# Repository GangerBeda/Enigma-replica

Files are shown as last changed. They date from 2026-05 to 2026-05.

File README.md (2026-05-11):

# Pico Enigma (MicroPython) – quick build & wiring guide

---

## 1) Parts checklist and central circuit setup

- Raspberry Pi Pico W
- 4× PCF8574 I²C GPIO expanders  
  - 2× for keyboard matrix  
  - 2× for LED matrix
- 3×9 key matrix (26 keys) wired as rows/columns
- 3×9 LED matrix / lampboard (26 LEDs, matrix wired)
- LCD1602 (HD44780) with I²C backpack (PCF8574)
  - Commonly available LCD displays with these specifications should fit, but just in case, this is the one used during development: <https://dratek.cz/arduino-platforma/1570-iic-i2c-display-lcd-1602-16x2-znaku-lcd-modul-modry.html>
- Half-sized breadboard, wires
- Resistors ~200 Ω for LEDs (For LED matrix at least 3 resistors)

- Put the microcontroller on the breadboard and connect any **GND** and **Vcc** to a bus strip and ground rail of the breadboard, using which you will power the individual subsystems.
- The 'box' model is the main casing component. Facing the front of the model, put the slotted breadboard to the back-right corner of the model.

---

## 2) 3D printed parts

- Print all the 3D parts in the 'Models' directory and its subdirectories.
- The models are made to be printed simply without supports. You can print with PLA, PETG, ABS, or virtually anything, but since some models have a large first layer, I recommend printing with PLA for simplicity and with a brim.
- You can assemble the subsystems along the way.

---

## 3) I²C buses and Pico pins

This project uses **two hardware I²C buses** plus one **SoftI²C**:

### Keyboard expanders (I²C0)
- Pico **GP0 = SDA0**
- Pico **GP1 = SCL0**
- PCF8574 addresses: **0x20** and **0x21**

### LED matrix expanders (I²C1)
- Pico **GP14 = SDA1**
- Pico **GP15 = SCL1**
- PCF8574 addresses: **0x22** and **0x23**

### LCD1602 (SoftI²C, separate)
- Pico **GP10 = SDA**
- Pico **GP11 = SCL**
- LCD backpack address: usually **0x27**

> All devices on the same I²C bus share SDA/SCL, but must have unique addresses.

---

## 4) PCF8574 address setup

PCF8574 boards have address jumpers A0/A1/A2.

Set them so you get:
- Keyboard: **0x20**, **0x21**
- LED: **0x22**, **0x23**
- LCD backpack: **0x27** (fixed by backpack or solder pads)

---

## 5) Keyboard assembly
- Install the key switches onto the 'keyboard' model.
- Wire the keyboard switches together into a matrix according to the following diagram.
              - diagram
- Slot the PCF8574 expanders into the 'keyboard circuitry' model via zipties or adhesive and secure the keyboard circuitry to the keyboard with the 'keyboard pivot'.

Keyboard uses two expanders:

### PCF8574 @ 0x20 (rows + cols 5–8)
- **P7 = row0**
- **P6 = row1**
- **P5 = row2**
- **P4 = col8**
- **P3 = col7**
- **P2 = col6**
- **P1 = col5**
- **P0 = unused**

### PCF8574 @ 0x21 (cols 0–4)
- **P4 = col4**
- **P3 = col3**
- **P2 = col2**
- **P1 = col1**
- **P0 = col0**

How to wire it physically:
- Connect each of the 3 **row wires** from your key matrix to the row pins above.
- Connect each of the 9 **column wires** to col0..col8 pins above.

- This completes the keyboard and you can now insert it into the 'box' casing.

---

## 6) LED “lampboard” assembly

- Print 26 of the 'led cup' models. Each of them has 2 openings at the base for LED terminals, one of which is marked with a + symbol for the anode.
- Prepare your 26 'led cups' by putting an LED in each one.
- Slot the 'led cups' in the 'lampboard frame' and solder them together according to the following diagram

    - diagram

### Circuit setup
LED matrix uses two expanders:

### PCF8574 @ 0x22 (columns 0–5)
- **P0 = col0** (hardware “col1”)
- **P1 = col1**
- **P2 = col2**
- **P3 = col3**
- **P4 = col4**
- **P5 = col5**
- **P6, P7 = unused**

### PCF8574 @ 0x23 (columns 6–8 + rows)
- **P0 = col6**
- **P1 = col7**
- **P2 = col8**
- **P3, P4 = unused**
- **P5 = row0**
- **P6 = row1**
- **P7 = row2**

How to wire it physically:
- Put the PCF8574 expanders in their slot on the 'lampboard circuitry' model and secure it with zip ties or adhesive. Then, attach the slotted lampboard circuitry to the wired lampboard frame.
- Connect the 3 **LED matrix row lines** to P5–P7 of **0x23**.
  - For the 3 rows, connect them to the expander via the 3 resistors. **This is important**, as without them, the LEDs will break.
- Connect LED matrix columns:
  - col0–col5 to **0x22 P0–P5**
  - col6–col8 to **0x23 P0–P2**

Polarity note:
- If **all lamps turn on at boot**, your matrix polarity is inverted relative to the default drive mode. The project has an **invert** option in the driver to fix this without rewiring.

---

## 7) LCD1602 wiring (I²C backpack)
- Slide the display into the 'display slot' model and connect it to the MCU.

- **SDA → GP10**
- **SCL → GP11**
- **VCC/GND** as required by your module
- The characters may not be visible at first. In that case, you can adjust the contrast using a potentiometer on the backpack of the display with a screwdriver.
  - Additionally, if you're powering the display with 3.3 V, you can try switching to 5 V, which should work better with LCD displays.
- Adjust the **contrast potentiometer** on the backpack if the backlight is on but characters are not visible.

- Attach the completed display slot to the lampboard frame.
  - This completes the lampboard. You can now put it into the 'box' casing model.
  - The replica should now be complete. Once you're done wiring the components to the MCU, you can put the 'box back' model on the back of the model and the 'keyboard lid' between the keyboard and the lampboard to seal the machine and the replica is completed.

---

## 8) Loading the program
- The replica has a small opening in the back. Use that to connect the Pico W to a computer.
- Install MicroPython firmware on the Pico W
  - Download the **Pico W** `.uf2` from
     <https://micropython.org/download/rp2-pico-w/>
  - Hold BOOTSEL, connect USB, drag the `.uf2` onto the `RPI-RP2` drive.
- Copy all eight source files from `micropython/` to the **root** of the Pico W filesystem.
  - Edit the 'wifi_config.py' file by inputing the ssid and password to your WiFi. This is needed for configuration.
  - You can use Thonny IDE to do this: Open each file from micropython/ -> Save As... -> Raspberry Pi Pico

- Once done, reset the controller and the program will run on startup, connect to the WiFi and display an IP address. Open the machine's address in a web browser (http). There, you'll find a configuration interface with instructions, which you can use to configure the machine's initial state.

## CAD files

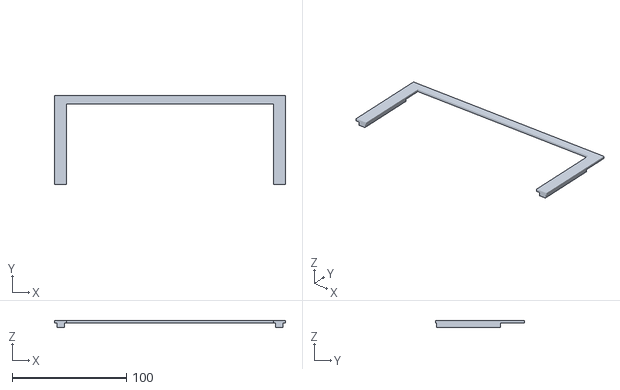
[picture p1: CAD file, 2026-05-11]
models/keyboard lid.stl
202.4 x 78.2 x 6.00

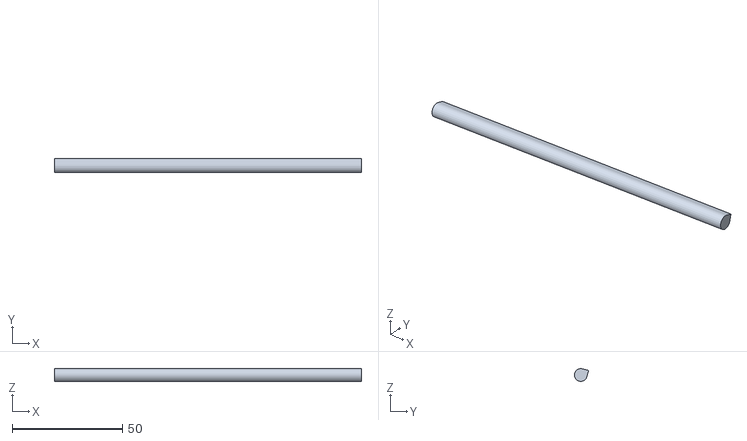
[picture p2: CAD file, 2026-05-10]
models/Keyboard/keyboard pivot.stl
139.0 x 6.45 x 5.80

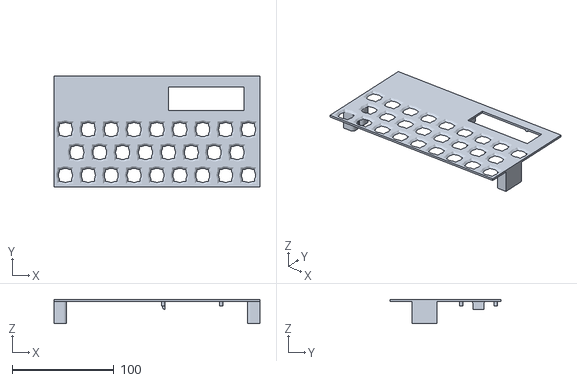
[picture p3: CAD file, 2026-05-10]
models/Lampboard/lampboard frame.stl
202.5 x 108.8 x 24.0

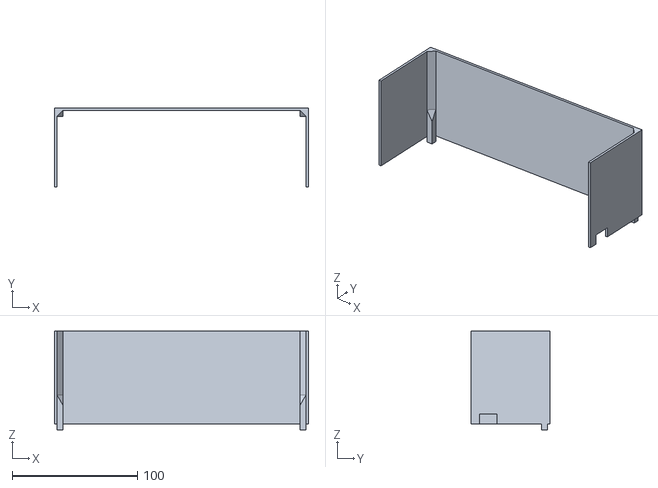
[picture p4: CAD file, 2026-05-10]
models/box back.stl
202.5 x 63.3 x 78.8

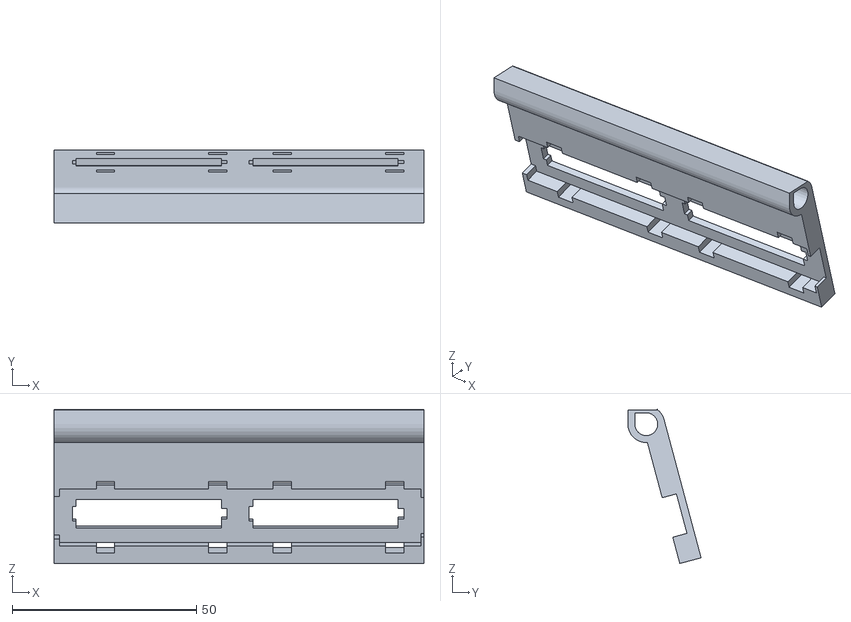
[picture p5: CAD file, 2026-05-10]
models/Keyboard/keyboard circuitry.stl
100.5 x 19.9 x 41.8

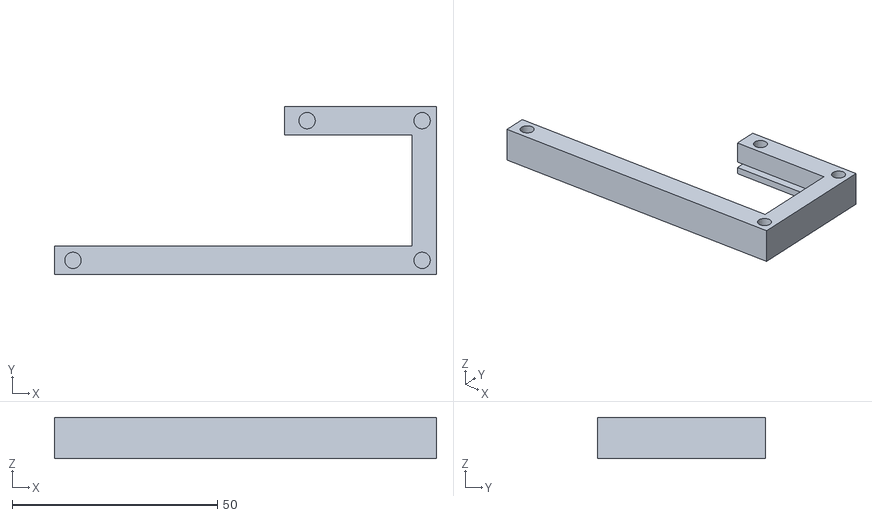
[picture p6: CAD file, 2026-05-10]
models/Lampboard/display slot.stl
93.0 x 41.0 x 10.0

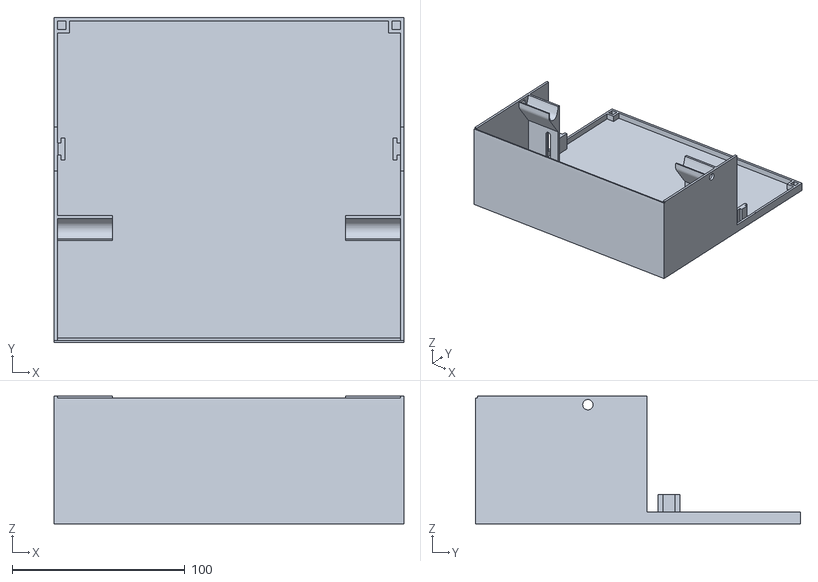
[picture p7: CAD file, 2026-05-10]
models/box.stl
202.5 x 188.0 x 74.0

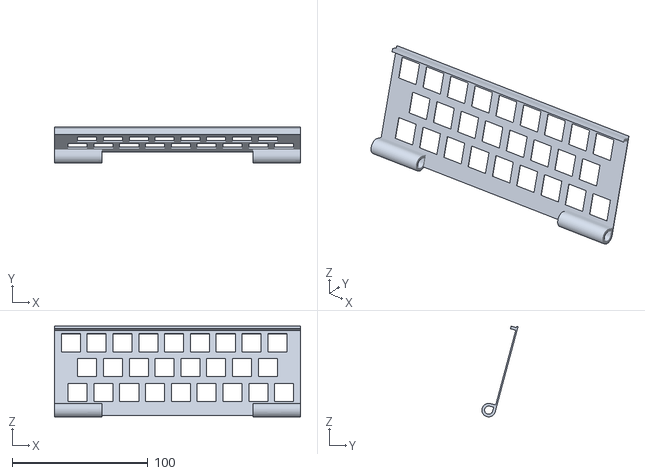
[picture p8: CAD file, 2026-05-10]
models/Keyboard/keyboard.stl
181.0 x 26.6 x 66.8

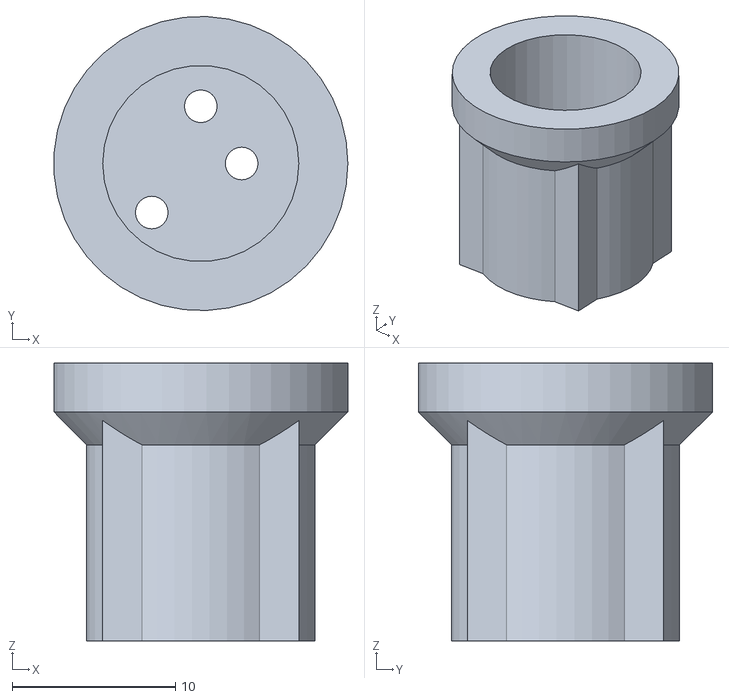
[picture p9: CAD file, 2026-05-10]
models/Lampboard/led res cup.stl
18.0 x 18.0 x 17.0

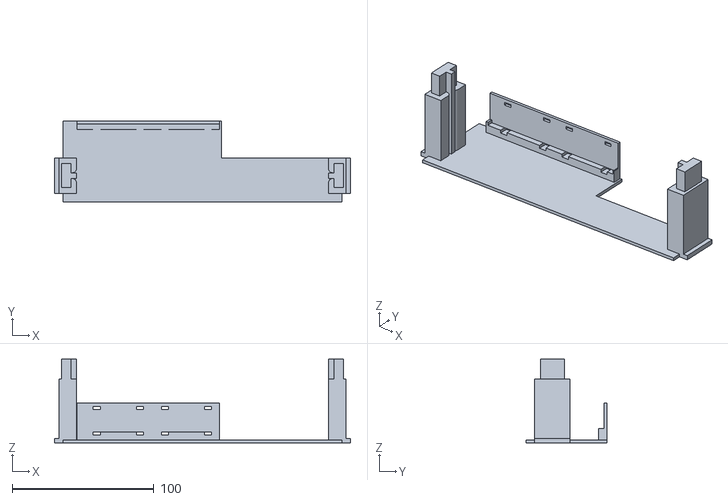
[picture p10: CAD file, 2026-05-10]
models/Lampboard/lampboard circuitry.stl
208.5 x 56.8 x 59.0

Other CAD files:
models/Lampboard/led cup.stl

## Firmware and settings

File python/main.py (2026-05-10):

# main.py
# Enigma machine entry point for Raspberry Pi Pico.
#
# Wiring summary:
#   Keyboard  I2C0 : SDA=GP0  SCL=GP1   expanders 0x20, 0x21
#   LED matrix I2C1: SDA=GP14 SCL=GP15  expanders 0x22, 0x23
#   LCD1602 SoftI2C: SDA=GP10 SCL=GP11  backpack 0x27

# Debug: when true, the lampboard class prints status over USB serial.
DEBUG = True

LED_MATRIX_INVERT = True

from enigma import Lampboard
from io_keyboard import KeyboardMatrix
from io_ledmatrix import LEDMatrix
from lcd1602_pcf8574 import LCD1602
from settings import load_settings, build_enigma
from web_server import connect_wifi, run_web_server
import _thread


def main():

    # Load persisted settings and build the machine
    settings = load_settings()
    
    # display_rotors[0] = left rotor, [1] = middle, [2] = right (fast)
    plugboard, rotor_system, display_rotors = build_enigma(settings)

    lampboard = Lampboard()

    # Hardware I/O
    keyboard  = KeyboardMatrix()
    led_matrix = LEDMatrix(invert=LED_MATRIX_INVERT)
    lcd       = LCD1602(sda_pin=10, scl_pin=11, address=0x27, cols=16, rows=2)
    lcd_ready = lcd.begin()
    last_lcd_positions = None

    # Initial display
    if DEBUG:
        lampboard.update_output(' ', ' ', plugboard)
        lampboard.display_rotor_states(display_rotors)
        if not lcd_ready:
            print("LCD1602 init failed on SoftI2C GP10/GP11 0x27.")

    if lcd_ready:
        last_lcd_positions = lcd.show_positions(
            [r.get_position() for r in display_rotors],
            last_positions=last_lcd_positions
        )

    # Wi-Fi + web configuration server
    ip = ""
    try:
        ip = connect_wifi()
        if ip:
            print("Web UI at http://{}/".format(ip))
            _thread.start_new_thread(run_web_server, (settings, ip))
        else:
            print("Web UI unavailable (no Wi-Fi connection).")
    except Exception as e:
        print("Wi-Fi / web server start failed:", e)
        ip = ""

    if lcd_ready:
        lcd.show_wifi_status(ip)

    print("Enigma machine ready – press a key.")



    # Main loop
    while True:
        # Read input from Keyboard
        user_input = keyboard.read_key()

        # Encryption path
        plugboard_output = plugboard.route(user_input)
        encrypted_char   = rotor_system.encrypt_char(plugboard_output)
        encrypted_char   = plugboard.route(encrypted_char)

        # Show output on Lampboard
        led_matrix.light(encrypted_char)

        if DEBUG:
            lampboard.update_output(user_input, encrypted_char, plugboard)
            lampboard.display_rotor_states(display_rotors)

        # Update rotor state display
        if lcd_ready:
            last_lcd_positions = lcd.show_positions(
                [r.get_position() for r in display_rotors],
                last_positions=last_lcd_positions
            )


main()

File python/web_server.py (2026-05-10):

# web_server.py
# Lightweight HTTP configuration server for the Enigma Pico.
#
# Serves a single-page web UI that lets the user set rotors, reflector, rotor positions and plugboard pairs.
# Applying the configuration saves the new settings to settings.json and calls
# machine.reset() so main.py picks them up immediately on the next boot.

import socket
import time
import machine

from settings import save_settings, ROTOR_WIRINGS, REFLECTOR_WIRINGS

def _url_decode(s):
    """Percent-decode a URL-encoded string to a string."""
    out = []
    i = 0
    while i < len(s):
        ch = s[i]
        if ch == '+':
            out.append(' ')
            i += 1
        elif ch == '%' and i + 2 < len(s):
            try:
                out.append(chr(int(s[i + 1:i + 3], 16)))
                i += 3
            except ValueError:
                out.append(ch)
                i += 1
        else:
            out.append(ch)
            i += 1
    return ''.join(out)


def _parse_form(body):
    """Parse application/x-www-form-urlencoded body to settings dict."""
    params = {}
    for part in body.split('&'):
        if '=' in part:
            k, v = part.split('=', 1)
            params[_url_decode(k)] = _url_decode(v)
    return params


_ROTOR_NAMES    = list(ROTOR_WIRINGS.keys())        # ["I", "II", "III", "IV", "V"]
_REFLECTOR_NAMES = list(REFLECTOR_WIRINGS.keys())   # ["UKW-A", "UKW-B", "UKW-C"]
_LETTERS        = [chr(65 + i) for i in range(26)]


def _select(name, options, selected):
    """Return an HTML <select> element string."""
    parts = ['<select name="', name, '">']
    for opt in options:
        sel = ' selected' if opt == selected else ''
        parts += ['<option value="', opt, '"', sel, '>', opt, '</option>']
    parts.append('</select>')
    return ''.join(parts)


def _build_page(settings, ip=""):
    """Return the full configuration page as a UTF-8 HTML string."""
    rotors    = settings.get("rotors",    ["I", "II", "III"])
    positions = settings.get("positions", ["A", "A", "A"])
    reflector = settings.get("reflector", "UKW-B")
    pairs     = settings.get("plugboard", [])

    # Plugboard pair badges with individual Remove forms
    pairs_html = []
    for pair in pairs:
        if isinstance(pair, (list, tuple)) and len(pair) == 2:
            plug_val = str(pair[0]).upper() + str(pair[1]).upper()
            pairs_html.append(
                '<form method="post" style="display:inline;margin:2px">'
                '<input type="hidden" name="action" value="remove_plug">'
                '<input type="hidden" name="plug" value="{v}">'
                '<button type="submit" class="pair-btn">'
                '{a}&#8596;{b} &#x2715;'
                '</button>'
                '</form>'.format(v=plug_val, a=pair[0], b=pair[1])
            )
    if not pairs_html:
        pairs_html = ['<em style="color:#888">No plugboard pairs.</em>']

    ip_line = (
        '<p class="note">Web UI address: '
        '<strong>http://{}/</strong></p>'.format(ip)
    ) if ip else ''

    r = rotors
    p = positions

    parts = [
        '<!DOCTYPE html><html><head><title>Enigma Config</title>',
        '<meta charset="utf-8">',
        '<meta name="viewport" content="width=device-width,initial-scale=1">',
        '<style>',
        'body{font-family:sans-serif;max-width:520px;margin:20px auto;padding:0 12px}',
        'h2{margin:18px 0 6px;padding-bottom:3px;border-bottom:1px solid #ccc}',
        'table{border-collapse:collapse;width:100%}',
        'th,td{padding:5px 8px;text-align:center}',
        'th{font-size:0.82em;color:#555;font-weight:normal}',
        'select{font-size:1em;padding:2px}',
        '.apply-btn{margin-top:16px;padding:9px 20px;background:#2a7;color:#fff;',
        'border:none;font-size:1.05em;border-radius:4px;cursor:pointer}',
        '.pair-btn{background:#ddd;border:1px solid #aaa;border-radius:3px;',
        'padding:3px 8px;cursor:pointer;font-size:0.95em}',
        '.note{font-size:0.82em;color:#666;margin-top:6px}',
        'hr{margin:20px 0;border:none;border-top:1px solid #ddd}',
        '</style></head><body>',
        '<h1>Enigma Config</h1>',
        ip_line,

        # ── Section 1: Plugboard (separate forms, no nesting issue) ───────────
        '<h2>Plugboard</h2>',
        '<div style="margin-bottom:6px">',
        ''.join(pairs_html),
        '</div>',
        # Add-pair form
        '<form method="post" style="margin-top:8px">',
        '<input type="hidden" name="action" value="add_plug">',
        '<label style="display:block;margin-bottom:4px">',
        'Add pair &ndash; two letters (e.g. <code>AM</code>):',
        '</label>',
        '<input type="text" name="plug" maxlength="2" size="5" '
        'style="font-size:1.1em;text-transform:uppercase">',
        ' <button type="submit" style="padding:4px 10px">Add pair</button>',
        '</form>',
        '<p class="note">Conflicting or duplicate pairs are resolved '
        'automatically by the plugboard logic on next boot.</p>',

        '<hr>',

        # ── Section 2: Main settings form (Apply & Reboot) ───────────────────
        '<form method="post">',
        '<input type="hidden" name="action" value="apply">',

        '<h2>Rotors &amp; Start Positions</h2>',
        '<table>',
        '<tr>',
        '<th></th>',
        '<th>Left rotor</th>',
        '<th>Middle rotor</th>',
        '<th>Right rotor<br><small>(fast)</small></th>',
        '</tr>',
        '<tr>',
        '<th style="text-align:right">Rotor</th>',
        '<td>', _select('rotor1', _ROTOR_NAMES, r[0] if len(r) > 0 else 'I'),   '</td>',
        '<td>', _select('rotor2', _ROTOR_NAMES, r[1] if len(r) > 1 else 'II'),  '</td>',
        '<td>', _select('rotor3', _ROTOR_NAMES, r[2] if len(r) > 2 else 'III'), '</td>',
        '</tr>',
        '<tr>',
        '<th style="text-align:right">Start pos.</th>',
        '<td>', _select('pos1', _LETTERS, p[0] if len(p) > 0 else 'A'), '</td>',
        '<td>', _select('pos2', _LETTERS, p[1] if len(p) > 1 else 'A'), '</td>',
        '<td>', _select('pos3', _LETTERS, p[2] if len(p) > 2 else 'A'), '</td>',
        '</tr>',
        '</table>',

        '<h2>Reflector</h2>',
        _select('reflector', _REFLECTOR_NAMES, reflector),

        '<p class="note">The current plugboard pairs (shown above) are '
        'included automatically when you apply.</p>',

        '<br>',
        '<button class="apply-btn" type="submit">Apply &amp; Reboot</button>',
        '<p class="note">Saves all settings to <code>settings.json</code> on '
        'the Pico W filesystem and reboots the device. Changes take effect '
        'after the reboot.</p>',

        '</form>',
        '</body></html>',
    ]
    return ''.join(parts)


# HTTP helpers
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

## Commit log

2026-05-11 Update README for user assembly guide
    Updated the README to provide a detailed quick build and wiring guide for the Pico Enigma project, including parts checklist, assembly instructions, and wiring setup.
2026-05-11 Fixed keyboard lid model
    [keyboard lid.stl]
2026-05-11 Update loading instructions for Pico W
